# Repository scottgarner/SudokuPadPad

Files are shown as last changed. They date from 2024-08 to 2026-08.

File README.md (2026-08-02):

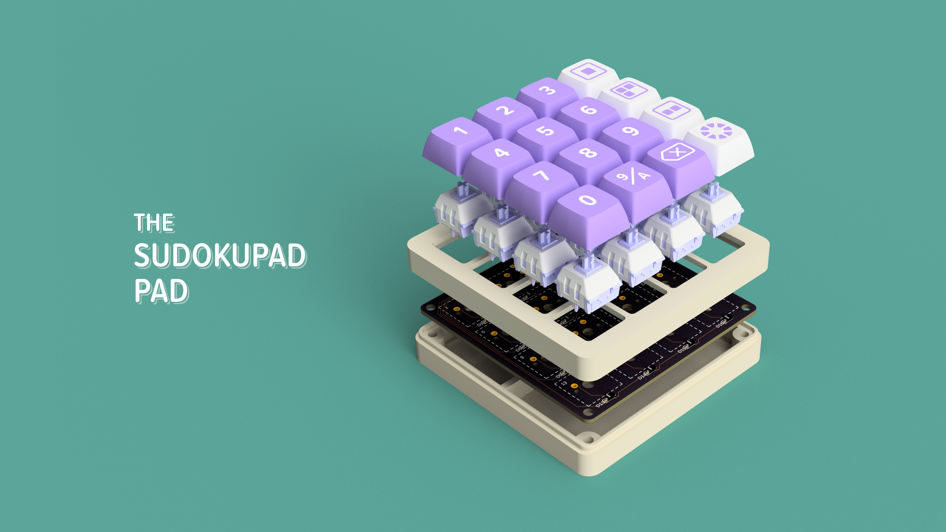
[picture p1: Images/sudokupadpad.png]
SudokuPad Pad


The SudokuPad Pad is a custom peripheral for [Sven Neumann’s SudokuPad](https://svencodes.com). For more [background information](https://scottmadethis.net/interactive/sudokupadpad/) see the project page.

## Making Your Own

Making your own SudokuPad Pad requires some basic soldering and 3d printing skills, as well as a small list of parts.

### Parts List

* 3D printed enclosure and keys in the CAD directory (see below).
* The custom circuit board in PCB (see below).
* A [Seeed Studio XIAO RP2040](https://www.seeedstudio.com/XIAO-RP2040-v1-0-p-5026.html) dev board (pre-soldered saves a step).
* 16 Cherry MX compatible keycaps of your choice ([example](https://www.adafruit.com/product/4955)).
* 16 1N4148 SMT SOD-123 diodes of your choice ([example](https://www.adafruit.com/product/5099)).

### 3D Printing

* The top and bottom parts of the enclosure should be very straightforward prints.
* The keycaps are a bit more complicated and are intended for a two-color printing with a .2mm nozzle.
* As an alternative to printing the keycaps, inexpensive blank white and purple keycaps are widely available.

### Custom PCB

* The Gerber export in the PCB directory can be uploaded to a service like [JLCPCB](https://jlcpcb.com) or [PCBWAY](https://www.pcbway.com) and purchased with more or less default settings.
* A stencil can be helpful, but the diodes are large enough to be soldered by hand.

## Soldering

The order of operations is slightly fussy because of the dual sided solder. My recommendation is:

1. Solder the diodes while everything is still flat and accessible.
2. Solder switch number 2.
3. Seat the Xiao and solder the headers in place on both sides of that switch.
4. Solder the remaining switches.

## Assembly

1. Place the PCB in the bottom half of the enclosure, aligning the USB-C port, and snap together.
2. Place the keycaps.

## Programming

1. Install the Arduino IDE.
2. See [Seeed Studio XIAO RP2040 with Arduino](https://wiki.seeedstudio.com/XIAO-RP2040-with-Arduino/) for IDE setup. 
3. Use the Arduino IDE to open Arduino/SudokuPadPad and write the sketch to the Xiao.

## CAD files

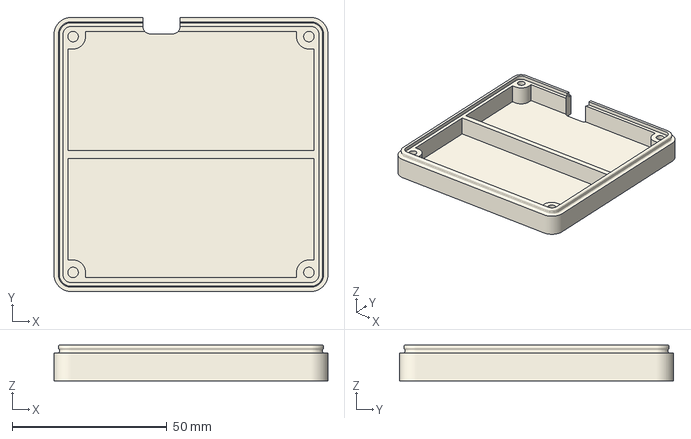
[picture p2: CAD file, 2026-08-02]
CAD/Base.3mf
88.6 x 88.6 x 11.6 mm

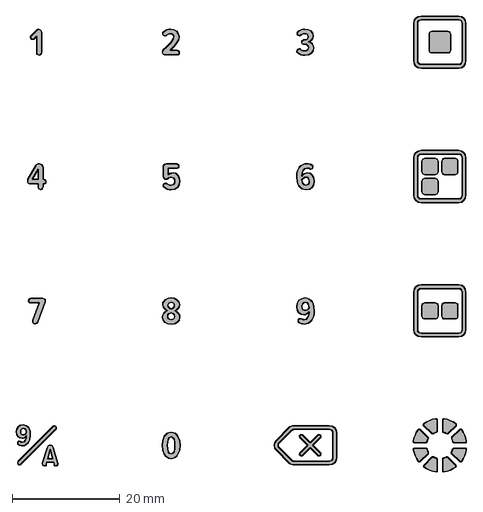
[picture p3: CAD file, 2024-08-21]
Design/Keycaps.dxf
83.8 x 84.8 mm

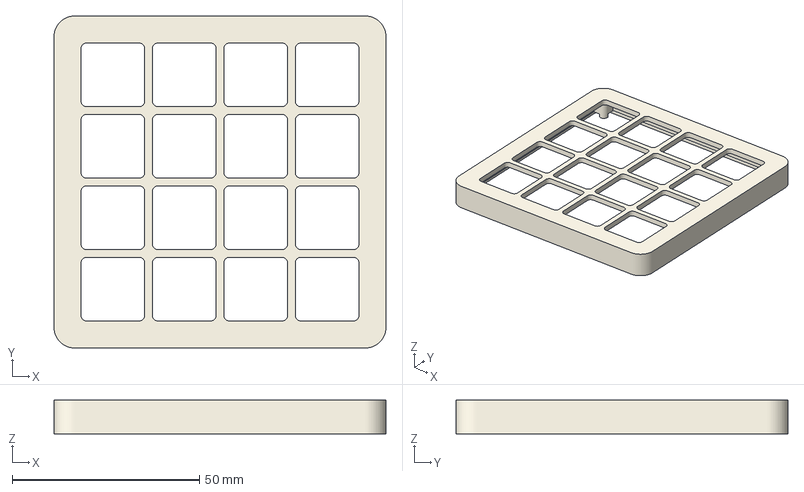
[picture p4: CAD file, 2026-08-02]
CAD/Top.3mf
88.6 x 88.6 x 8.95 mm

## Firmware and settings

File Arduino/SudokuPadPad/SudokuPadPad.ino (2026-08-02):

#include <Keyboard.h>
#include <EEPROM.h>

#define DEBOUNCE_DELAY 8
#define EEPROM_ADDR 0
#define LAYOUT_COUNT 2

struct Color {
  PinStatus r, g, b;
};

struct Button {
  char key;
  bool currentState = HIGH;
  bool lastState = HIGH;
  unsigned long lastChange = 0;
};

enum Layout : uint8_t {
  LAYOUT_DESCENDING = 0,  // 7-8-9 on top
  LAYOUT_ASCENDING = 1,   // 1-2-3 on top
};

const int rowCount = 4;
const int columnCount = 4;
const int rowPins[rowCount] = { D7, D8, D9, D10 };
const int colPins[columnCount] = { D6, D5, D4, D3 };
Button buttons[rowCount][columnCount];

uint8_t layout = LAYOUT_DESCENDING;

const char layoutKeys[LAYOUT_COUNT][16] = {
  // LAYOUT_DESCENDING: 7-8-9 / 4-5-6 / 1-2-3
  { KEY_KP_7, KEY_KP_8, KEY_KP_9, 'z',
    KEY_KP_4, KEY_KP_5, KEY_KP_6, 'x',
    KEY_KP_1, KEY_KP_2, KEY_KP_3, 'c',
    KEY_KP_0, KEY_TAB, KEY_BACKSPACE, 'v' },
  // LAYOUT_ASCENDING: 1-2-3 / 4-5-6 / 7-8-9
  { KEY_KP_1, KEY_KP_2, KEY_KP_3, 'z',
    KEY_KP_4, KEY_KP_5, KEY_KP_6, 'x',
    KEY_KP_7, KEY_KP_8, KEY_KP_9, 'c',
    KEY_KP_0, KEY_TAB, KEY_BACKSPACE, 'v' },
};

const Color layoutColors[] = {
  { HIGH, LOW, HIGH },
  { HIGH, HIGH, LOW },
};

void setLED(Color c) {
  digitalWrite(PIN_LED_R, c.r);
  digitalWrite(PIN_LED_G, c.g);
  digitalWrite(PIN_LED_B, c.b);
}

const Color LED_OFF = { HIGH, HIGH, HIGH };

uint16_t pressedMask = 0;

void setup() {

  // Initialize LED.
  {
    pinMode(PIN_LED_R, OUTPUT);
    pinMode(PIN_LED_G, OUTPUT);
    pinMode(PIN_LED_B, OUTPUT);
  }

  // Initialize pins.
  {
    for (int i = 0; i < rowCount; i++) {
      pinMode(rowPins[i], OUTPUT);
      digitalWrite(rowPins[i], HIGH);
    }
    for (int j = 0; j < columnCount; j++) {
      pinMode(colPins[j], INPUT_PULLUP);
    }
  }

  // Wait for serial.
  Serial.begin(9600);
  while (!Serial && millis() < 2000) {
  }

  // Check for boot-mode override (hold a key while plugging in).
  {
    EEPROM.begin(256);

    // Read single key by position.
    auto held = [](int row, int col) -> bool {
      digitalWrite(rowPins[row], LOW);
      delayMicroseconds(10);
      bool pressed = (digitalRead(colPins[col]) == LOW);
      digitalWrite(rowPins[row], HIGH);
      return pressed;
    };

    if (held(3, 3)) {
      Serial.println("Entering bootloader mode...");
      rp2040.rebootToBootloader();
    } else if (held(0, 0)) {
      Serial.println("Setting ascending layout...");
      EEPROM.write(EEPROM_ADDR, LAYOUT_ASCENDING);
      EEPROM.commit();
    } else if (held(2, 0)) {
      Serial.println("Setting descending layout...");
      EEPROM.write(EEPROM_ADDR, LAYOUT_DESCENDING);
      EEPROM.commit();
    }

      // Load layout or default to ascending.
      uint8_t stored = EEPROM.read(EEPROM_ADDR);
    layout = (stored < LAYOUT_COUNT)
               ? stored
               : LAYOUT_DESCENDING;

    Serial.print("Loaded layout: ");
    Serial.println(layout);
  }

  // Initialize buttons.
  {
    buttons[0][0] = { layoutKeys[layout][0] };
    buttons[0][1] = { layoutKeys[layout][1] };
    buttons[0][2] = { layoutKeys[layout][2] };
    buttons[0][3] = { layoutKeys[layout][3] };
    buttons[1][0] = { layoutKeys[layout][4] };
    buttons[1][1] = { layoutKeys[layout][5] };
    buttons[1][2] = { layoutKeys[layout][6] };
    buttons[1][3] = { layoutKeys[layout][7] };
    buttons[2][0] = { layoutKeys[layout][8] };
    buttons[2][1] = { layoutKeys[layout][9] };
    buttons[2][2] = { layoutKeys[layout][10] };
    buttons[2][3] = { layoutKeys[layout][11] };
    buttons[3][0] = { layoutKeys[layout][12] };
    buttons[3][1] = { layoutKeys[layout][13] };
    buttons[3][2] = { layoutKeys[layout][14] };
    buttons[3][3] = { layoutKeys[layout][15] };
  }

  // Keyboard initialization.
  Keyboard.begin();
}

void loop() {

  for (int i = 0; i < rowCount; i++) {
    digitalWrite(rowPins[i], LOW);

    for (int j = 0; j < columnCount; j++) {
      bool state = digitalRead(colPins[j]);
      Button &button = buttons[i][j];

      // Raw reading changed, restart debounce timer.
      if (state != button.lastState) {
        button.lastChange = millis();
      }

      // Debounce passed, and state changed.
      if (millis() - button.lastChange >= DEBOUNCE_DELAY) {
        if (state != button.currentState) {
          button.currentState = state;

          byte buttonIndex = (i * 4) + j;

          if (button.currentState == LOW) {
            Keyboard.press(button.key);
            Serial.print("Key pressed: ");
            Serial.print(i);
            Serial.print(", ");
            Serial.println(j);

            pressedMask |= (uint16_t(1) << buttonIndex);
          } else {
            Keyboard.release(button.key);
            Serial.print("Key released: ");
            Serial.print(i);
            Serial.print(", ");
            Serial.println(j);

            pressedMask &= ~(uint16_t(1) << buttonIndex);
          }
        }
      }

      button.lastState = state;
    }

    digitalWrite(rowPins[i], HIGH);
  }

  if (pressedMask) {
    setLED(layoutColors[layout]);
  } else {
    setLED(LED_OFF);
  }
}

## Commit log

2024-08-21 Key updates and LED.
2024-08-21 Design files.
    [Keycaps.dxf]
2026-06-16 Add PCB data.
2026-06-17 Debounce tweaks and typo fix.
    [SudokuPadPad.ino]
2026-08-02 Add CAD files for 3d prints.
    [Base.3mf, Top.3mf]
2026-08-02 Add README for SudokuPad Pad project
    Added detailed instructions for creating and assembling the SudokuPad Pad, including parts list, 3D printing guidelines, soldering steps, and programming instructions.
